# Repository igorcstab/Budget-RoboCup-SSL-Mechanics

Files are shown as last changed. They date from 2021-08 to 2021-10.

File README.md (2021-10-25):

# Licensing
Long story short, the Open Source Hardware Association (OSHWA) basycally says although you can use the software licenses for hardware, it's not ideal. Also, if you really open the GNU GPL license text, for example, and read it once in your life, you'll have to agree it's only suited for software even though people use it for other types of products. So the OSHWA suggests the use of a software license for licensing software, a dedicated license for documentation and a proper hardware license on your project.

For that reason, the **Documentation** of this project is licensed under **CC-BY-SA** (although I didn't bother to put the CC logos everywhere) and the **Hardware** under the **CERN-OHL-W-V2**. Kind of the GNU GPL equivalents. Both can be found at the **Licenses folder**.

Also, everything used in this project is open-source/free software so anyone could have full access to all files. For the CAD, it was used **FreeCAD**, for the Documentation the **LibreOffice** package.

# About me
At the moment I'm a Electrical Engineering with Electronics Emphasis student at São Carlos School of Engineering at University of São Paulo ([EESC-USP](https://eesc.usp.br/en/)), member of the Warthog Robotics (WR) team with 5.5 years of experience in mobile robotics and in this project I also intend to share some of my maintenance, design, research and competition experience to help you make your project decisions. You can check my [Linkedin Profile](https://www.linkedin.com/in/igorsantabarbara/) or reach me here on GitHub.

# Why another SSL robot?
It's been a while all SSL teams around the world use the same-ish robot, agree on most of the design decisions and there's little to explore specially when it comes to Hardware Design. Even though, I decided to make my own version for two reasons:
1. Most of the designs come from teams with ***very generous*** sponsorships and budgets but that's not the reality undergraduate students (specially in "developing" countries) or even hobbists who are willing to take the challenge face. So the first point is to **provide a design that can be taken completely, as a template or modified** to fulfill the needs of your project, explaining my design decisions and making it more or less a "how to make you own SSL robot" guide. That's because although the League forces the teams to contribute their breakthroughs via a document called Team Description Paper (TDP), the information is still sparse and sometimes not well described/documented.
2. In my experience, I'd say it's quite easy to be an engineer with nearly infinite budget. When you can get electronic components from Digikey or Mouser in less than a week, use carbon fiber everywhere you want or some fancy 3D printing/thousand-axis CNC machining, designing hardware is a trivial ~~if not boring~~ task. With all that put, the other point is to **incentivise or inspire more people and organizations to join the field of mobile robotics or to step up their game**.

# Repository Organization
I'm borrowing the project file system we use at WR because I think it's well suited to organize this kind of project:
- DOC - stands for "Documentation"; self-explanatory.
- DST - stands for "Distribution"; it contains the results/products/outcomes of the source files. Basically what you'd need to manufacture the robot, for example, 2D drawings for machined parts, .steps to make your own G-Code, etc. 
- SRC - stands for "Source"; it contains CAD files, mainly.

Besides, there'll be a README.md file everywhere I find interesting to explain a design decision, tell about my experience on a subject or explain/give the background on a point.

Also, I'm going to use a V-Model to organize the development but don't expect an Aerospace-grade Systems Engineering. I'll keep things way simpler just to use the model more on the mindset side of the things instead of really going deep in each step and validation.

So, basically this V-Model-thing it's more about how/where the project starts and ends. With that put, I suggest going first to the Documentation (but of course, if you're not interested, you can just go right to the CAD files or something else).

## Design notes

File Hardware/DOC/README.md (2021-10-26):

 # Operation

A SSL bot during the competition, testing or maintenance has some operation particularities that should be met in the scope of hardware design in order to avoid headaches and make our lives easier. Those are being able to:

- Access the electronics and battery quickly;
- Repair a system without rendering the whole robot inoperative;
- Change the unified vision blobs easily;
- Have as little cable harness as possible (and organizing them, obviously);
- Keep a low center of gravity and be as lightweight as possible;
- Mitigate carpet contamination and clean the robot easily;

It doesn't look like much but those atributes will produce a lot of requisites or force design decisions. Pay attention to the fact each of those itens tells us **what** to do but not **how**.

# Requisites and Architecture

The Requisites are almost all rules related but there are a few that comes from somewhere else. For example, the omniwheels. Actually, using wheels could be a requisite and that document could easily have a hundred lines if we over-system-engineer it. But as I already wrote, it only exists to organize the workflow and ideas instead of pretending I work at Boeing.

The Architecture is structured as a Work Breakdown Structure (WBS) and is already something more or less subjective and if I review this part a few weeks from now I'll definitely disagree with the way I organized a few itens. Either way, this part of the Documentation has the purpose of guiding our mental efforts on decision making and our CAD organization instead of perfectly controlling how the project goes.

# Design Decisions

## Locomotion Motors

The motors I have available are those: [Locomotion Motors](https://microred.com.br/page18.html).

loc_motor

Also, because we're trying to cut costs the most we can, I'm going to use 3 motors per robot. Definitely 4 motors are better but 3 is the minimal number we should need to make our omnidirectional robot functional and it works decently (specially if you have access to more powerful motors and even better if you could have encoders). You could (actually, should) disagree with that decision but when you see that with 24 motors, you could manufacture 6 robots with 4 motors each while you'd need 18 motors for the same 6 bots team if they had 3 motors each, you can see there's a point at least. In fact, if you had 24 motors at your disposition, you could have 8 bots using 3 motors. That's 2 extra robots to substitute during the game. At least interesting, specially if they don't have batteries to play the full game. 

As we're talking about a soccer team, it means we should have more than a single robot. So competing in this category is much different than others that you'd need only one robot to perform a task. Here, each extra cost gets multiplied by the number of bots you intend to bring to the game. In the Division A, they play with 11 bots. Here, we're aiming at the Division B, as the intention would be entering the category, which is played with 6 bots and a smaller field. I could believe someone can make a 3-bots team work, but that would take a lot of programming effort and still would be a tough match against a 6 bots team because at each kickoff/fault/etc you'd have 1 robot to kick the ball. This way, is hard to keep coordination of the robots and keep them well positioned. So add the fact that's an AI that's taking those decisions and it's just not realistic imagine you'd have a chance. I believe that a 4-bots team should be able to play against any 6-bots team and it's a good number to give to your programming folks to test their ideas, implement strategies and adapt the behavior during a game. Any number beyond that is just a pay-to-win-ish way of improving the quality of your team instead of making they actually play better. Of course 6 is better than 4, but "code is free" while 2 extra robots increase your budget by 50%! During the 2019 Latin America Robotics Competition (LARC), I watched the best SSL game of my life between RoboCIn and Whartog Robotics B (which is our rookie's team. Basically we take some folks that don't know why you can plug your phone charger on the wall upside down and put them to design a whole SSL robot in the span of a year). It was a crazy close game that ended on 3x2 or 4x3 (I can't remember) for WR-B on overtime after both teams comebacks. RoboCIn has a pretty neat team with newly manufatured parts and they even compete internationally on Robocup Division B while WR-B had just a poor mechanics designed somewhere around 2014/15 with a straight kicker and a dream. I'd accept the claim "it was a fluke" because WR-B was playing worse although they won the game but that's only because they where at numeric and design disadvantage. Also the game went to overtime tied on 2x2 or something like that. Deserved.  Another case of that in my experience is the LARC 2016 Finals between RoboFei and WR, when WR 4 bots killing it. Anyway, just proving my point that 4 is a number that's good enough.

## Shaft Attachment

When it's not possible to remove the shaft from the motor, we'd have to design a hub to attach the wheel to the shaft instead of doing something stupid and ending with steel dust/chips inside the motor, degrading its lifetime. In my case, I'm going to design a hub anyway because I'm opting to leave the shaft as it is instead of making keyways, glueing a spur gear or whatnot. Also, **I'm not sure** about the material of the shaft but I'm assuming it's some stainless steel series. So, picking a material for the hub is not trivial given the many choices we have. Still, I don't believe you could make it resistant enough with regular PLA filament even with 100% infill and machining from a plastic like POM or PVC, altough exciting to experiment with in order to test if it would be eligible, it would still need a lot of inserts for the screws. Steel is granted to work. Same with many other metals like brass. So we'd like to have a material that isn't very expensive and that has good properties. Usually, copper alloys are more expensive and have specific applications which aren't being targeted here. Aluminium could work, but stainless steel in contact with aluminium reacts on a galvanic corrosion, weakening the hub. Wheter this is significant to our application, is questionable. Regular steel would be a good choice but the rust is a great downside in my opinion. So I choosed 304 stainless steel because is primarily easy to find, has a slightly higher price than aluminium, is machinable, not weldable (which is a desired feature, I guess?) and granted to work.

## Wheels

Scouting some old team's TDPs (Team Description Paper, which is a document teams from all around the world make telling what they do/did with their bots), we can already look for a trend on wheel diameter in order to make our first decision regarding that. Also, we know the basic concept: a small (diameter-wise) wheel produces more torque in cost of less displacement. What I found was a trend that the biggest wheels are about 60mm of diameter, while the smallest are about 45mm and sizes live somewhere in the middle gaussianly. Kind of. But most of the teams use pretty powerful motors when compared to what I have avaliable. So as one of their motors has more power than my whole robot, my decision is to stick at the low sized wheels to not bite off more than I can chew and to maximize the torque. My robots won't be able to run all over the field but they should work properly.

The number of sub-wheels/rubber wheels/whatever (which I'll call "O-rings" here) is not that critical. Numbers usually range from 15 to 20-ish. 

# Future Improvements

My project doesn't feature many functionalities both because it is minimalistic and meant to incentivise your own upgrades. Actually you don't **need** a dribbler or angled kicker. So if you want to cut everything down, you can even just go for the "straight kicker and a dream". Still, the following list contains some aspects to guide where you should start looking to reach a Division A, international tier design:

- A major improvement the robot could recieve is a dampened kicking system so when it intercepts the opponent or recieves a pass, the ball won't just bounce of the robot and go randomly somewhere;
- Upgrading to 4 motors, with higher power rating or of other type such as BLDC;
- Having encoders on the motors because there's basically no ~~decent~~ way to design a controller for the robot if you can't close the loop;
- Getting an IMU. It's a cool tool for the guys messing with the Control but it's more an electronics upgrade than something that should concern us. Even though, we should be aware of that and not design any wacky part for the robot: just try to keep everything balanced, symetric and don't stick anything in the middle of the bot;

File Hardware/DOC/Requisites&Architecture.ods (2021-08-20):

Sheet: Requisites
Requisite | Reason | Importance | Validation
Compliance with all Robocup rules | Being allowed at the League’s competitions | Mandatory | By the rules document, check if there’s a point that disqualifies the robot for competition
Have access to the robot electronics and batteries in less than 30s | Charging batteries, changing the robot’s ID, substituting boards or cable harnesses are common tasks that should be performed swiftly | Important | Time the ID change, battery access or similar
Have a straight kick device | You can’t rely on pushing the ball at this category by just slamming | Important | Give the kick command and check if the robot kicks the ball
The robot must not present risk to itself, other robots or humans | Robocup rule + you don’t want to damage anything or hurt anyone | Mandatory | By the rules document, check if there’s a point that disqualifies the robot for competition
The robot must not damage or modify the ball or the field | Robocup rule + you don’t want to damage anything or hurt anyone | Mandatory | Make a test game and check the ball integrity
The robot must not interfere with the vision system | Robocup rule + you don’t want to get disqualified | Mandatory | Check if there’s any vision disturbance provoked by the robot
A robot must not tip over, break or drop parts on the field | Robocup rule + you don’t want to damage anything or hurt anyone | Mandatory | Check that while moving, the robot doesn’t tips over, breaks or drops parts that pose a potential threat to other robots
The robot must be modular | Being able to repair a system without rendering the whole robot inoperative facilitates maintenance and makes the substitution for spare parts more agile | Important | Being able to disassemble a sector of the robot without having to disassemble another one to have access to the first one
Have a dribbling device | This device is what makes the game a game and not only a bunch of robots kicking at any direction | Desirable | Check the dribbling device working as described in the Robocup rules
The robot must fit a 180mm diam x 150mm height cylinder | Robocup rule + you don’t want to get disqualified | Mandatory | Measure the manufactured robot dimensions
The dribbling device must not elevate the ball from the ground | Robocup rule + you don’t want to get disqualified | Mandatory | Confirm the ball stays on the ground while being dribbled
Other robot must be capable of removing the ball of the dribbling robot | Robocup rule + otherwise it wouldn’t be a fair game | Mandatory | Check if its possible to take the ball out of the robot, when being dribbled, with your own hands
A robot must not take full control of the ball by removing all of its degrees of freedom | Robocup rule + otherwise it wouldn’t be a fair game | Mandatory | Analyze if the ball still has all its degrees of freedom when being dribbled
80% of the area of the ball when viewed from above has to be outside the convex hull around the robot | Robocup rule + you don’t want to get disqualified | Mandatory | Measure the ball area covered by the robot
The robot must not accelerate the ball more than 6.5m/s | Robocup rule + otherwise it wouldn’t be a fair game | Mandatory | Measure the ball speed when kicked by the robot
Use omnidirectional wheels | It’s the trademark of the League, great to translate in any direction or to rotate on the robot’s axis and nearly everyone implements it | Important | Check the robot’s capacity to translate in any direction and to rotate on its own axis
The bot must use the unified vision system for its identification | Robocup rule + you don’t want to get disqualified | Mandatory | Check if the robot is correctly identified when using the Robocup unified vision pattern
Have a angled kick device | Grants a major advantage during penalty kicks | Important | Give the command to angle the kicker and check the robot kicks the ball at the commanded angle

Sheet: Architecture
Robot Project
Locomotion |  | Kicker |  |  | Structure |  |  | Documentation
Drivetrain | Wheels | Straight Kick Device | Angled Kick Device | Dribbling Device | Chassis | Columns | Cover | Manufacturing Guidelines | Systems Engineering | BOM
Hub | Omniwheel | Solenoid | Servo | Roller | First Floor |  | Robot Cover | 3D Printing Guidelines | READMEs | Parts List
Locomotion Motor | Wheel Rollers | Kicker Plate | Drive | Motor | Electronics Floor |  | Blobs | 2D Drawings | Requisites and Architecture | Service Quotation
Mounting Plate |  |  |  | Drive | Columns |  |  |  |  | Materials Quotation

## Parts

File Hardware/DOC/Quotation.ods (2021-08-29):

Part | Material | Part Length [mm] | Cut Thickness [mm] | Parts Needed | Stock Length Needed [mm] | Stock OD [in] | Stock Length [mm] | Average Price | # Stock Needed | Final Price
Wheel Hub | Stainless 304 | 4 | 1 | 12 | 61 | ½ | 500 | 50,00 BRL | 1 | 50,00 BRL

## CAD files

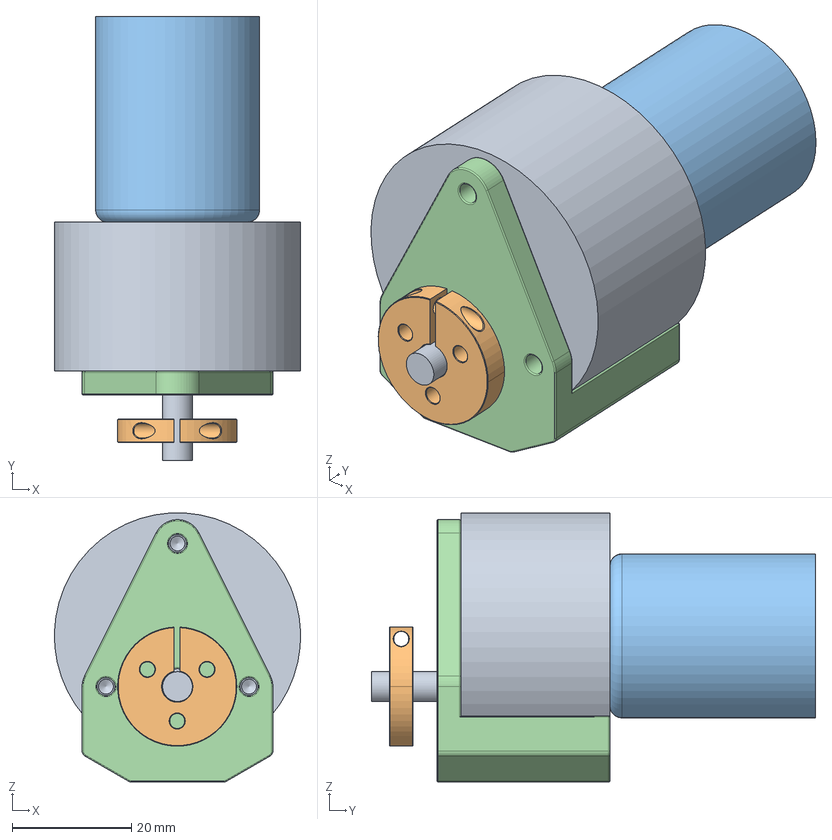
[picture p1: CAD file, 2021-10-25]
Hardware/SRC/Full Robot.FCStd
41.3 x 74.5 x 45.1 mm
Gearbox
Wheel Hub
DC Motor
Underside

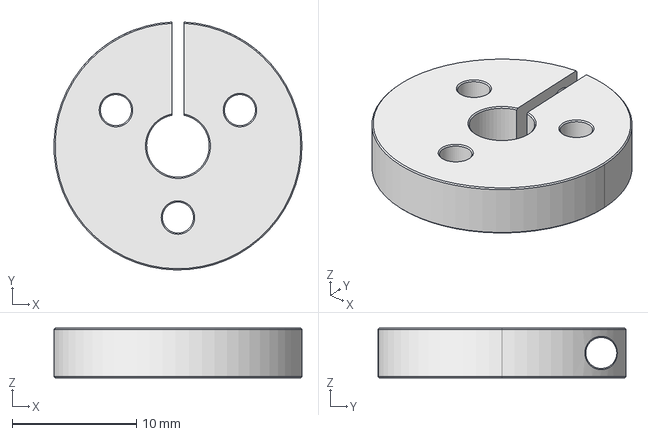
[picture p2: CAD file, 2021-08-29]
Hardware/SRC/Drivetrain/Wheel Hub.FCStd
20.0 x 20.0 x 4.00 mm

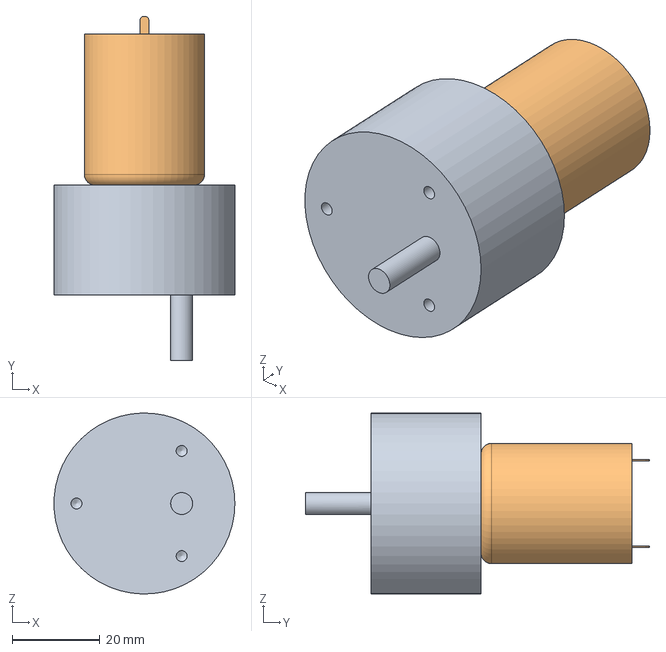
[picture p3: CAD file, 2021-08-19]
Hardware/SRC/Drivetrain/Locomotion Motor.FCStd
41.3 x 78.5 x 41.3 mm
Gearbox
DC Motor

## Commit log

2021-08-16 Renamed rules document. Architecture still incomplete
    [Requisites&Architecture.ods]
2021-08-18 Modelled motor, ball and battery
2021-08-19 Mounting Holes added to Gearbox
2021-08-20 Finished Architecture
    [Requisites&Architecture.ods]
2021-08-29 Added Wheel Hub and Quotation
    [Quotation.ods, Wheel Hub.FCStd]
2021-10-25 Finally decided on a motor bracket design
    [Full Robot.FCStd, Locomotion Motor.FCStd, Wheel Hub.FCStd]
